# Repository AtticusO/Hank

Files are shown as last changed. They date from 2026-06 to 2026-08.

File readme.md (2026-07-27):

# Hank
Hank is a friendly robotic arm bartender, he can play songs from spotify which the user can select on a locally hosted html page, Hank will also be capable of being controlled through different modes, firstly arrow keys and the press of a key on the keyboard such as r to reset its position, secondly through typed commands, and finally through position adjustment determined by a YOLO inference model which will orient the robot toward the empty cup

## Running Hank (on the Raspberry Pi)

1. **Servo daemon** — the servos use pigpio, which needs its daemon running:
   `sudo pigpiod`
2. **Vision + personality loop** — `python main.py` (camera window, cup/person detection, distance-based reactions)
3. **Keyboard arm control** — `python orientation.py` (arrow keys: left/right = waist, up/down = shoulder, Esc quits)
4. **Servo command line** — `python servo_ops.py` (commands like `jab`, `wave`, `curl`, or angles like `70,50` / `0,70,50`)

## Music page

1. Create a Spotify app at https://developer.spotify.com/dashboard and export:
   `SPOTIPY_CLIENT_ID`, `SPOTIPY_CLIENT_SECRET`, `SPOTIPY_REDIRECT_URI`
2. For playback on the Pi itself install [raspotify](https://github.com/dtcooper/raspotify) so the Pi shows up as a Spotify Connect device (needs Spotify Premium). Otherwise playback goes to any open Spotify app on your account.
3. `python server.py`, then open `http://<pi-ip>:8080` from any phone/laptop on the same network.
   The first run prints a Spotify login URL — open it and paste the redirect URL back into the terminal once.

## Install

```
pip install -r requirements.txt
sudo apt install python3-picamera2   # Pi camera library comes from apt, not pip
```

## TODO (not really in order that much)
1. Adjust 3D models & print and adjust again and print and adjust again
2. Create queue in server.py for song selection
3. Actually make personality.py
4. Clean up servo functions in orientation.py so im not recreating same or similar variables across functions when i dont need to (actually idk about this one its a good idea but most are just writing cords to move_servo() and im sorta of fine with that well see, file does need to be cleaned up a bit tho)
5. Actually attatch cup detection to servo movement
6. Get distance.py working and implement distance detection into movement
7. $ Set up some bash files to automatically configure bluetooth to connect to a PS5 controller $ DONE : WORKS
8. Make mock servos so I can test on devices other than rasp pi
9. Wire buttons and implement code for choosing mode of operation such as bartender or controlled
10. Make dance functions with bpm from spotify
11. Add all the infrastructure for raspotify 
12. Tie everything together in a somewhat cohesive process in main.py

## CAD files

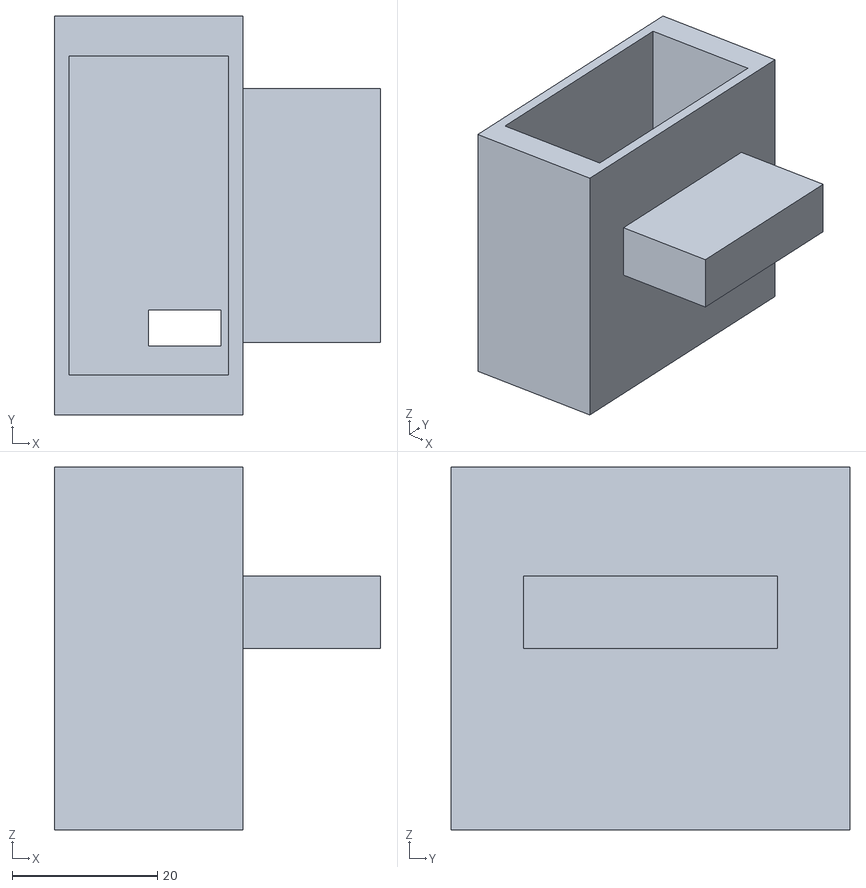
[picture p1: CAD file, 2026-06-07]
Design/H-1/Elbow_Servo_Case-Body.stl
45.0 x 55.0 x 50.0

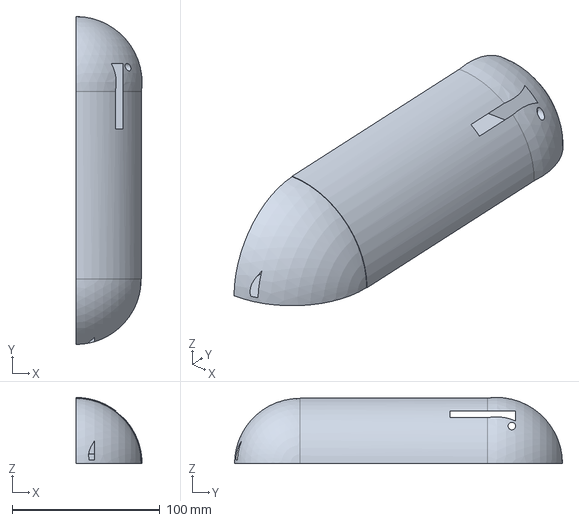
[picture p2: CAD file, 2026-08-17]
Design/H-2/Arm_Two.FCStd
44.8 x 222.0 x 44.8 mm

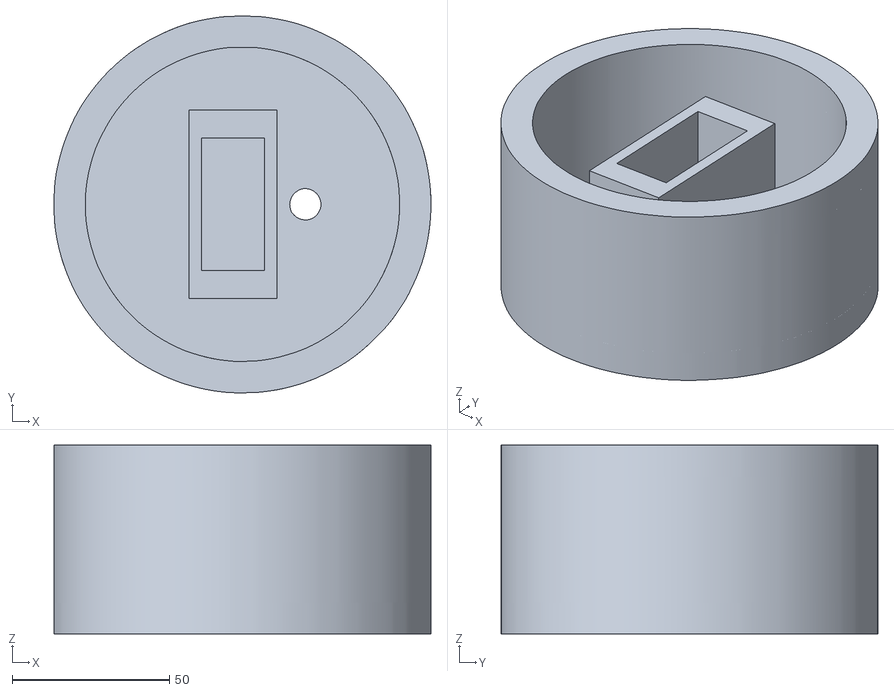
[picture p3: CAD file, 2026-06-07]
Design/H-1/Servo_Base_Cyl_Attatchment.stl
119.9 x 119.8 x 60.0

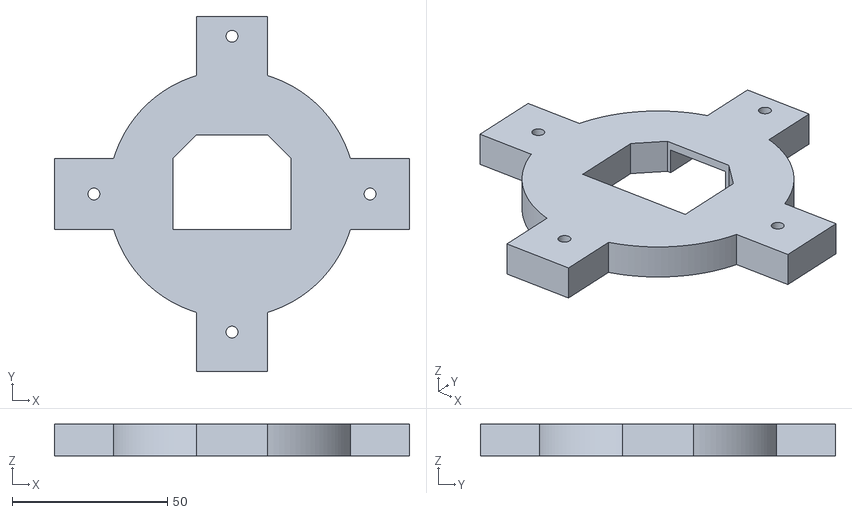
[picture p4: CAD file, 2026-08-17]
Design/H-2/Waist_Adapter_Two-Body.stl
114.3 x 114.3 x 10.2

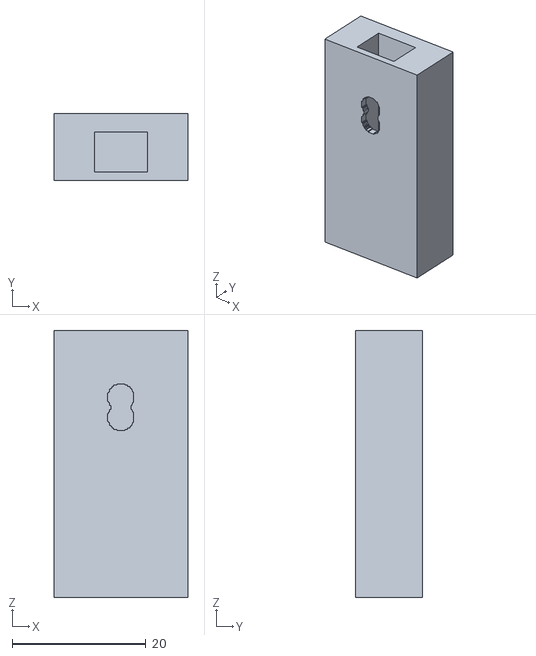
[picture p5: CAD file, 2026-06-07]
Design/H-1/Servo_Adapter.stl
20.0 x 10.0 x 40.0

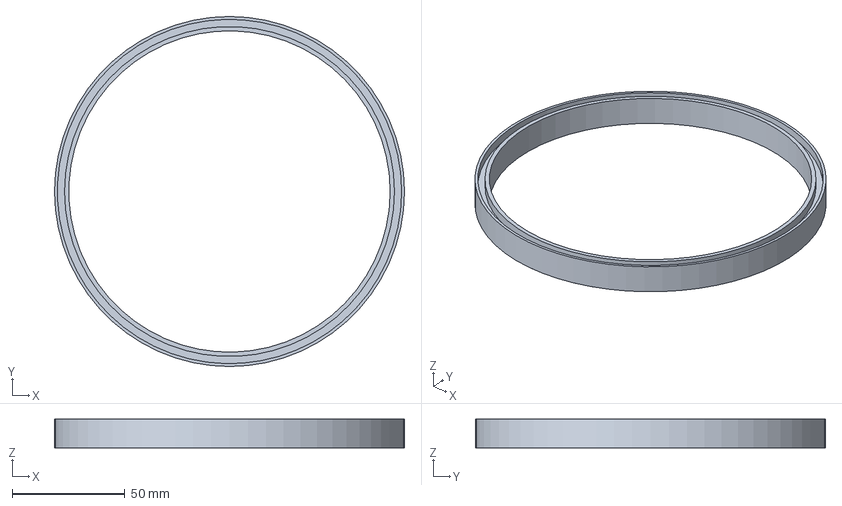
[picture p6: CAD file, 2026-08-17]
Design/H-2/Waist_Ball_Bearing_Cage.FCStd
154.9 x 154.9 x 12.7 mm

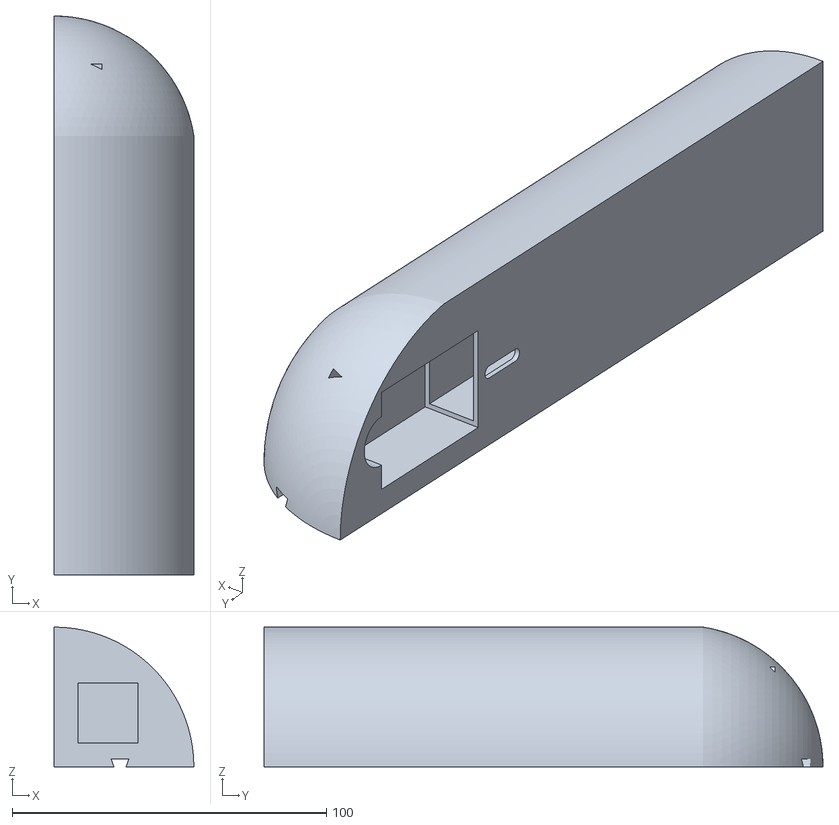
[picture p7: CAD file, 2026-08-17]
Design/H-2/ForeArm_Two-Body.stl
44.5 x 177.8 x 44.5

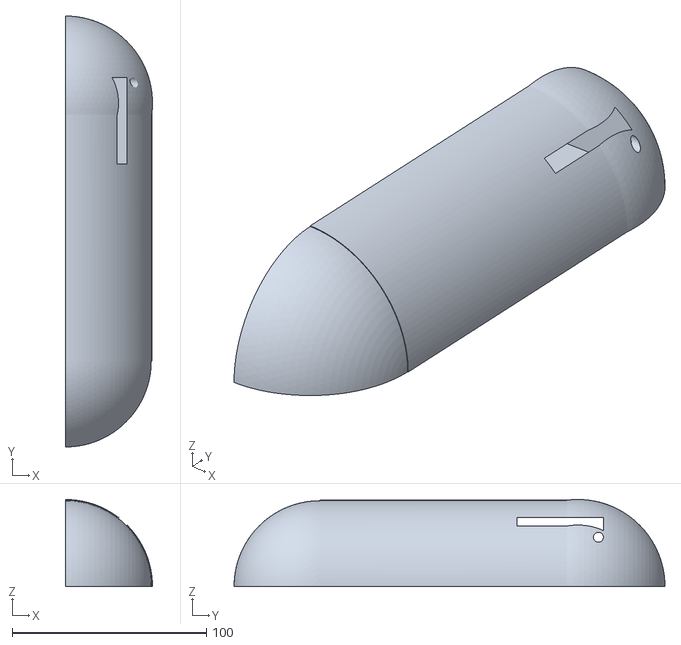
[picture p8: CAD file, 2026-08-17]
Design/H-2/Arm_Two-Body.stl
44.8 x 222.0 x 44.8

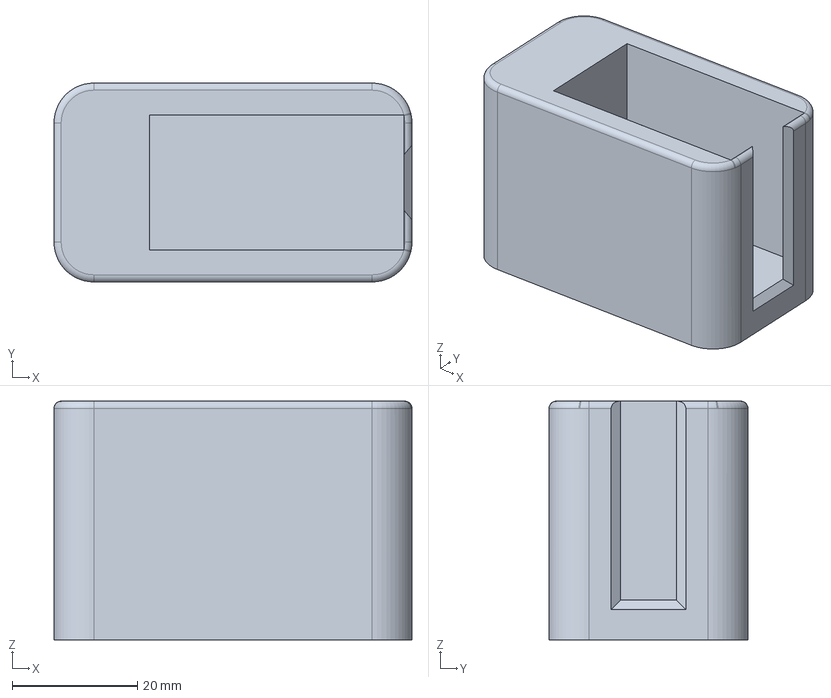
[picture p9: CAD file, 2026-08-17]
Design/H-2/Servo_Case_Two.FCStd
57.1 x 31.8 x 38.1 mm

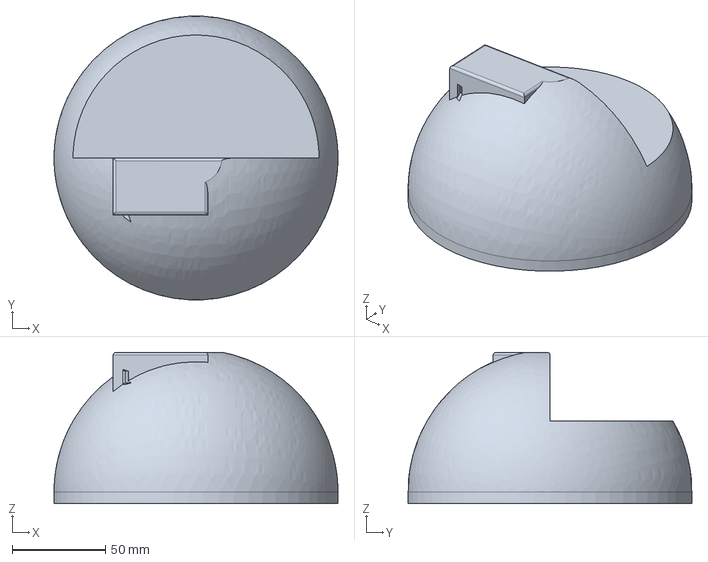
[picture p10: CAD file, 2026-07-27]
Design/H-2/Hemisphere_Two.FCStd
152.4 x 152.2 x 81.3 mm

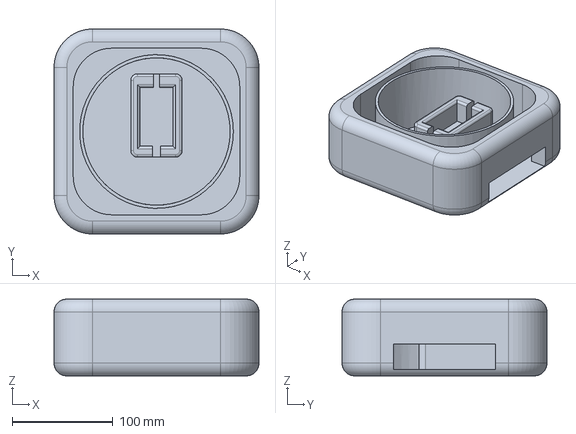
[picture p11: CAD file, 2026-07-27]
Design/H-2/Square_Base_Two.FCStd
203.2 x 203.2 x 76.2 mm

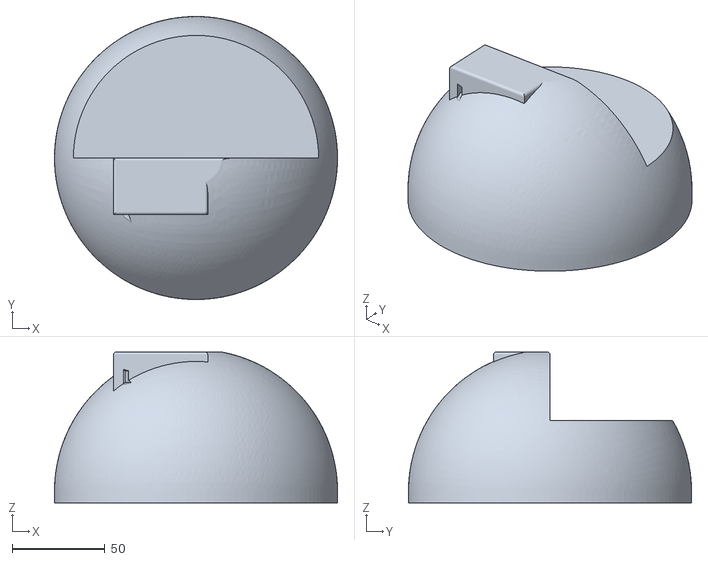
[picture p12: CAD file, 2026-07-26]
Design/H-2/Hemisphere_Two-Body.stl
152.4 x 152.4 x 81.3

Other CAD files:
Design/H-2/Waist_Ball_Bearing_Cage-Body.stl
Design/H-2/Waist_Adapter_Two.FCStd
Design/H-2/Servo_Case_Two-Body.stl
Design/H-2/Square_Base_Two-Body.stl
Design/H-2/ForeArm_Two.FCStd

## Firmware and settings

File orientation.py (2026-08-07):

import servo_ops
import asyncio
import time
from evdev import InputDevice, list_devices, categorize, ecodes
import select

class positions:
    def __init__(self):
        self.servos = servo_ops.move()
        self.orient = {"waist" : self.servos.angles["waist"],
                       "shoulder" : self.servos.angles["shoulder"],
                       "elbow" : self.servos.angles["elbow"]}
        self.pos_log = []
        for tags in self.orient:
            self.pos_log.append(self.orient[tags])

    ## Keeps orient/pos_log in sync with what the servos actually did,
    ## since the servo layer clamps angles to [-90, 90]
    def _sync_state(self):
        for i, name in enumerate(("waist", "shoulder", "elbow")):
            self.orient[name] = self.servos.angles[name]
            self.pos_log[i] = self.servos.angles[name]

    def _sync_logs(self):
        for i, n in enumerate(("waist", "shoulder", "elbow")):
            self.orient[n] = self.pos_log[i]


    ## Moves servos asyncronously
    ## servo_pos is a list of [waist, shoulder, elbow] positions
    async def move_servo(self, servo_pos, delays=None):
        for i in range(len(servo_pos)):
            #print(servo_pos[i])
            #print(f"MOVING TO :: {servo_pos[i]}")
            await asyncio.gather(
                self.servos.move_waist(servo_pos[i][0]),
                self.servos.move_shoulder(servo_pos[i][1]),
                self.servos.move_elbow(servo_pos[i][2])
            )
            if delays and i < len(delays) and delays[i] is not None:
                await asyncio.sleep(delays[i])
            self._sync_state()

    ## generates and returns servo positional array, posit_array, instead of directly calling servo movement
    ## output from these functions get passed into the move_servo() function to update servo position
    ## all of these functions return a list of servo degree positions in a [[waist,shoulder,elbow]] format
    def waist(self, deg):
        new_pos = int(self.orient["waist"] + deg)
        return [[new_pos, self.orient["shoulder"], self.orient["elbow"]]]

    def shoulder(self, deg):
        new_pos = int(self.orient["shoulder"] + deg)
        return [[self.orient["waist"], new_pos, self.orient["elbow"]]]

    def elbow(self, deg):
        new_pos = int(self.orient["elbow"] + deg)
        return [[self.orient["waist"], self.orient["shoulder"], new_pos]]

    ## Additive Rotations for servos
    ## These are plain sync methods: each one is a single top-level
    ## asyncio.run() call, so they can be used from normal code anywhere
    ## Changes waist position incrementally
    def rotate_waist(self, deg):
        asyncio.run(self.move_servo(self.waist(deg), [0.1]))

    ## Changes shoulder position incrementally
    def rotate_shoulder(self, deg):
        asyncio.run(self.move_servo(self.shoulder(deg), [0.1]))

    ## Changes elbow position incrementally
    def rotate_elbow(self, deg):
        asyncio.run(self.move_servo(self.elbow(deg), [0.1]))

    ###########################
    ### Arm Movements for keyboard control
    def reach(self, deg):
        new_shoulder = self.orient["shoulder"] + deg

        ## elbow follows the shoulder a little further to keep the reach straight
        if deg > 0:
            new_elbow = self.orient["elbow"] + deg + 10
        elif deg < 0:
            new_elbow = self.orient["elbow"] + deg - 10
        else:
            new_elbow = self.orient["elbow"]

        posit_array = [[self.orient["waist"], new_shoulder, new_elbow]]
        asyncio.run(self.move_servo(posit_array))

    def rotate(self, deg):
        new_pos = self.orient["waist"] + deg
        posit_array = [[new_pos, self.orient["shoulder"], self.orient["elbow"]]]
        asyncio.run(self.move_servo(posit_array))


    #### Preset Movements and Orientations

    ## Dance Moves and stuff
    def dance(self, bpm, playing=True):
        sync = abs(int((bpm / 60)*3))
        self.center()
        self.bounce(sync, "right")
            #time.sleep(1)
            #self.bounce(sync, "left")
            #time.sleep(1)

    def bounce(self, rate, dir):
        ## Capture the start pose once so the return waypoint is exact even
        ## if the extended pose gets clamped by the servo layer.
        base = list(self.pos_log)
        sign = -1 if dir == "left" else 1
        print("LEFT" if sign < 0 else "RIGHT")

        ## Arc out to the side (waist swings in `dir`, shoulder lifts, elbow
        ## tucks), then return to the captured base pose.
        out = [base[0] + sign * rate, base[1] + rate, base[2] - rate]
        back = [base[0], base[1], base[2]]

        pos = [out, back]
        delays = [0.5, 0.3]

        print(f"Pos: {pos}\nRate: {rate}\nDir: {dir}")
        asyncio.run(self.move_servo(pos, delays))
        


    ## Sets orientation for fist bump and loads to servo
    def fist_bump(self):
        posit_array = []
        delays = []
        if self.orient["shoulder"] != 70 or self.orient["elbow"] != 50:
            posit_array.append([0, 70, 50])
            delays.append(0.5)
        posit_array.append([0, 20, -10])
        delays.append(1)
        posit_array.append([0, 70, 50])
        delays.append(0.5)

        asyncio.run(self.move_servo(posit_array, delays))

    def jab(self):
        posit_array = []
        delays = []
        if self.orient["shoulder"] != 70 or self.orient["elbow"] != 50:
            posit_array.append([0, 70, 50])
            delays.append(0.2)
        posit_array.append([0, -40, -80])
        delays.append(0.1)
        posit_array.append([0, 70, 50])
        delays.append(0.1)

        asyncio.run(self.move_servo(posit_array, delays))

    def reset(self):
        asyncio.run(self.move_servo([[0, 70, 50]], [0.5]))

    def curl(self):
        asyncio.run(self.move_servo([[0, 0, 90]], [0.4]))

    def point(self):
        asyncio.run(self.move_servo([[0, 0, -90]], [0.2]))

    def center(self):
        asyncio.run(self.move_servo([[45, 45, 45]], [0.1]))
    ### Different Waves for greetings
    def wave(self):
        posit_array = []
        delays = []
        posit_array.append([0, 70, self.orient["elbow"]])
        delays.append(0.4)
        posit_array.append([0, 70, 50])
        delays.append(0.01)
        posit_array.append([0, 70, -30])
        delays.append(0.2)
        posit_array.append([0, 70, 50])
        delays.append(0.01)
        posit_array.append([0, 70, -30])
        delays.append(0.2)

        asyncio.run(self.move_servo(posit_array, delays))
        self.reset()

    def wave_one(self):
        posit_array = []
        delays = []
        posit_array.append([0, 70, self.orient["elbow"]])
        delays.append(0.4)
        posit_array.append([0, 70, 50])
        delays.append(0.01)
        posit_array.append([0, 70, -30])
        delays.append(0.2)
        posit_array.append([0, 70, 50])
        delays.append(0.01)
        posit_array.append([0, 70, -30])
        delays.append(0.2)

        asyncio.run(self.move_servo(posit_array, delays))
        self.reset()

    def wave_two(self):
        posit_array = []
        delays = []
        posit_array.append([0, 70, -90])
        delays.append(0.4)
        posit_array.append([20, self.orient["shoulder"], self.orient["elbow"]])
        delays.append(0.01)
        posit_array.append([0, self.orient["shoulder"], self.orient["elbow"]])
        delays.append(0.2)
        posit_array.append([-20, self.orient["shoulder"], self.orient["elbow"]])
        delays.append(0.01)

        asyncio.run(self.move_servo(posit_array, delays))
        self.reset()

    def bounce_left(self):
        posit_array = []
        delays = []
        posit_array.append([-30, 30, 10])
        delays.append(0.2)
        posit_array.append([-70, 70, 50])
        delays.append(0.01)
        posit_array.append([-30, 30, 10])
        delays.append(0.2)
        posit_array.append([0, 70, 50])
        delays.append(0.2)

        asyncio.run(self.move_servo(posit_array, delays))
        self.reset()

    def bounce_right(self):
        posit_array = []
        delays = []
        posit_array.append([30, 30, 10])
        delays.append(0.2)
        posit_array.append([70, 70, 50])
        delays.append(0.01)
        posit_array.append([30, 30, 10])
        delays.append(0.2)
        posit_array.append([0, 70, 50])
        delays.append(0.2)

        asyncio.run(self.move_servo(posit_array, delays))
        self.reset()

    ## Keyboard hold controls

    def find_keyboard(self):
        for path in list_devices():
            dev = InputDevice(path)
            keys = dev.capabilities().get(ecodes.EV_KEY, [])
            if ecodes.KEY_A in keys and ecodes.KEY_UP in keys:
                return dev
        raise RuntimeError("No keyboard found in /dev/input")

    def listen_hold(self):
        """Hold-aware loop: tracks which keys are currently held and acts
        repeatedly while they stay down, independent of OS key-repeat rate.
        Left/right rotate the waist, up/down raise/lower the shoulder."""
        dev = self.find_keyboard()
        print(f"Listening on {dev.path} ({dev.name})")
        held = set()

        while True:
            # Wait up to 0.05s for input; returns immediately if a key event is ready.
            r, _, _ = select.select([dev.fd], [], [], 0.05)
            if r:
                for event in dev.read():
                    if event.type != ecodes.EV_KEY:
                        continue
                    key = categorize(event)
                    if key.keystate == key.key_down:
                        held.add(key.keycode)
                    elif key.keystate == key.key_up:
                        held.discard(key.keycode)

            if "KEY_ESC" in held:
                break

            # This block runs ~20x/sec for as long as a key stays held.
            moved = False
            if "KEY_UP" in held:
                print("UP PRESSED")
                self.pos_log[1] -= 5
                moved = True

            if "KEY_DOWN" in held:
                print("DOWN PRESSED")
                self.pos_log[1] += 5
                moved = True

            
            if "KEY_LEFT" in held:
                print("LEFT PRESSED")
                self.pos_log[0] -= 5
                moved = True

            if "KEY_RIGHT" in held:
                print("RIGHT PRESSED")
                self.pos_log[0] += 5
                moved = True

            
            
            if "KEY_W" in held:
                print("LEFT PRESSED")
                self.pos_log[2] -= 5
                moved = True

            if "KEY_E" in held:
                print("RIGHT PRESSED")
                self.pos_log[2] += 5
                moved = True
            
            if "KEY_A" in held:
                print("LEFT PRESSED")
                self.pos_log[1] -= 5
                moved = True

            if "KEY_D" in held:
                print("RIGHT PRESSED")
                self.pos_log[1] += 5
                moved = True
            
            if "KEY_Z" in held:
                print("LEFT PRESSED")
                self.pos_log[0] -= 5
                moved = True

            if "KEY_X" in held:
                print("RIGHT PRESSED")
                self.pos_log[0] += 5
                moved = True




            if "KEY_R" in held:
                print("RESET PRESSED")
                self.reset()
            if "KEY_P" in held:
                print("POINT PRESSED")
                self.point()
            if "KEY_C" in held:
                print("CURL PRESSED")
                self.curl()
            if moved:
                # move_servo expects a list of [waist, shoulder, elbow] rows
                asyncio.run(self.move_servo([list(self.pos_log)]))

    ## Keyboard press controls
    def listen_press(self):
        dev = self.find_keyboard()

        print(f"Listening on {dev.path} ({dev.name})")
        for event in dev.read_loop():
            if event.type != ecodes.EV_KEY:
                continue
            key = categorize(event)
            if key.keystate != key.key_down:   # only on press, ignore release/hold
                continue
            if key.keycode == "KEY_UP":
                print("UP PRESSED")
                self.reach(-30)
            elif key.keycode == "KEY_DOWN":
                print("DOWN PRESSED")
                self.reach(30)
            elif key.keycode == "KEY_LEFT":
                print("LEFT PRESSED")
                self.rotate(30)
            elif key.keycode == "KEY_RIGHT":
                print("RIGHT PRESSED")
                self.rotate(-30)
            elif key.keycode == "KEY_R":
                print("RESET PRESSED")
                self.reset()
            elif key.keycode == "KEY_C":
                print("CURL PRESSED")
                self.curl()
            elif key.keycode == "KEY_ESC":
                break


if __name__ == "__main__":
    p = positions()
    print("\n $$$   Hank Orientation System   $$$ \n")
    settings = 2
    if settings == 0:
        print("Keyboard Controls: \n")
        p.reset()
        p.listen_hold()
    elif settings == 1:
        while True:
            print("\n")
            x = input("Enter Orientation >>> ")
            print("\n")
            if x == "curl" or x == "cu":
                p.curl()
            elif x == "fb" or x == "b":
                p.fist_bump()
            elif x == "reset" or x == "r":
                p.reset()
            elif x == "wave" or x == "w":
                p.wave()
            elif x == "point" or x == "p" or x == "pt":
                p.point()
            elif x == "jab" or x == "j":
                p.jab()
            elif x == "br":
                p.bounce_right()
            elif x == "bl":
                p.bounce_left()
            elif x == "waist":
                p.rotate_waist(10)
                time.sleep(0.5)
                p.rotate_waist(-10)
    elif settings == 2:
        bpm = input("Enter BPM >>> ")
        p.dance(int(bpm))
        #p.bounce(20, "right")

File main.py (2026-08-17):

import cam_ops
import obj_detection
import personality
import orientation
#import distance
import cv2
#import ps5_controls
import server


class Hank:
    ## Hank owns every piece of hardware exactly once and shares references;
    ## creating a second Cam or servo stack crashes on the Pi
    def __init__(self):
        self.cam = cam_ops.Cam(0)
        self.detector = obj_detection.detect()
        self.arm = orientation.positions()
        #self.measure = distance.measure()
        self.pers = personality.acts(self.arm)
        self.ps5 = None



    def detect(self, frame):
        annotated_frame, tags, cords = self.detector.detection(frame)
        return annotated_frame, tags, cords

    def video(self):
        f_count = 0
        while True:
            frame = self.cam.stream()
            if frame is None:
                continue

            annotated_frame, tags, cords = self.detect(frame)
            f_count += 1

            ## React every few frames so servo moves don't stall the video
            if f_count > 2 and len(tags) > 0:
                #d = self.measure.dist()
                self.pers.follow(tags, cords)
                f_count = 0

            cv2.imshow("Hank View", annotated_frame)
            if cv2.waitKey(1) == ord('q'):
                break
        cv2.destroyAllWindows()
        self.cam.stop()

    ## Mode control, setting mode 0 is bartender, mode 1 is keys control ([w,e],[a,d],[z,x]), 
    ## setting mode 2 is PS5 Controller
    def mode(self, setting):
        if setting == 1:
            self.arm.reset()
            self.arm.listen_hold()
        elif setting == 2:
            pass
            #self.ps5 = ps5_controls.Controller(self.arm)
            #while True:
            #    c.remote()
            #    if c.cancel == True:
            #        break
        elif setting == 3:
            print("Starting Hank Music Server")
            server._start_server()
        

if __name__ == "__main__":
    print("Executing Hank Protocals")
    h = Hank()
    setting = 0
    if setting != 0:
        h.mode(setting)
    else:
        h.video()

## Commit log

2026-06-07 Add file structure and add cam_ops and detection
    [Arm_Two.FCStd, Elbow_Servo_Case-Body.stl, Servo_Adapter.stl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]
2026-06-09 Arm Two stl file upload
    [Arm_Two-Body.stl, Arm_Two.FCStd]
2026-06-11 Editted Arm Designs, also added to servo ops, using gpiozero for servos
    [Arm_Two-Body.stl, Arm_Two.FCStd, Elbow_Servo_Case-Body.stl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]
2026-06-12 Added to servo_ops and made functions async for smoother servos
2026-06-12 set up servo movement and added hardcoded moves, need to make into functions
2026-06-12 tested on pi and servo code works, fixed bugs in orientation and added loop to take input to call position functions
    [orientation.py, servo_ops.py]
2026-06-14 fixed yolo model bugs on raspberry pi,hook up servos to computer vision to a degree, waist servo not working idk why
    [cam_ops.py, main.py, obj_detection.py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]
2026-06-15 added some orientations, waist now moves with avg x value of an identified person, need battery pack because pi crashes when i move all three servos
    [orientation.py, personality.py, servo_ops.py]
2026-06-16 created square base, edited forearm, some minor code changes
    [Arm_Two - Copy.FCStd, ForeArm_Two-Body.stl, ForeArm_Two.FCStd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]
2026-06-18 updated 3d models like square base two and hemisphere two, added structures to measure distance, altered personality to act as more of a module and created structure for reactions to distance
    [Hemisphere_Two.FCStd, Servo_Case_Two.FCStd, Square_Base_Two.FCStd]
2026-06-23 stl file stuff, servo case adn hemisphere changes
    [Hemisphere_Two-Body.stl, Hemisphere_Two.FCStd, Servo_Case_Two-Body.stl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]
2026-06-26 Fixed Arrow Controls on rasp pi
    [cam_ops.py, music.py, orientation.py]
2026-06-28 Added some arrow key hold control features, needs to be fixed because theres an error with how the async function are running when calling servo movemnet functions for arrow key controls, i just put 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
    [music.py, orientation.py]
2026-07-08 fixed async issues im pretty sure maybe
    [music.py, orientation.py]
2026-07-13 added alot, fixed async function issue with key controls, changed library used for server to http.server and urllib instead of socket and uses json to play songs from the index.html file which is hos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
    [cam_ops.py, distance.py, main.py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]
2026-07-14 finally wired battery to servos so i can control all 3 motors without crashing the pi, works pretty good, distance thing is still not working well might have to replace the part
    [distance.py, orientation.py]
2026-07-15 Added a python file to allow controll through a ps5 controller, left stick shoulder right stick elbow and triggers for waist, got stick pos detection just need to connect to servos right way through 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
    [orientation.py, ps5_controls.py]
2026-07-17 added other features to ps5 file such as buttons mapped to commands like curl jab or reset, also added trigger detection mapped to the waist servo to rotate the arm
    [ps5_controls.py]
2026-07-23 built out spotipy so i have authentication set up so music playing through the lan site will be done soon
    [Hemisphere_Two.FCStd, Square_Base_Two-Body.stl, Square_Base_Two.FCStd]
2026-07-23 fixed music uri redirect errors and also fixed errors in server.py, spotipy now works pretty well i just wanna adjust the html a bit in index.html but its looking good for now, need to write code to 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
    [music.py, server.py]
2026-07-25 Adjusted models because I fixed my ender 3 so i can acutally print now, server.py prints the correct lan ip now and starts spotify before doing anything that needs it maybe i will start spotify in th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
    [Hemisphere_Two-Body.stl, Hemisphere_Two.FCStd, Square_Base_Two-Body.stl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]
2026-07-26 added basic stuff for dance functions in orientation.py, also changed some stuff about the Arm 3d design and also fixed issues with the circular base 3d design, need to test the basic stuff for dance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
    [Arm_Two.FCStd]
2026-07-26 built out bounce and dance a little more, not actually working on the servos, will fix tomorrow cause idk why the seros arent moving because the orient dictionary and pos log list is updating on call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
    [orientation.py]
2026-07-26 added a bash file to configure bluetooth connection, I need to write code to run it in main when ps5 controller mode is in use, I also added a mode function to main.py which handles which mode the ro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
    [main.py, orientation.py, ps5_controls.py]
2026-07-27 Maybe possibly might of fixed bounce function in orientation so dance function might work now, also worked on servo case 3d design because the square base finally finished printing after 2.5 days als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
    [Hemisphere_Two.FCStd, Servo_Case_Two.FCStd, Square_Base_Two.FCStd]
2026-07-31 fixed dance to some extent, still need to make it actually bounce to a bpm and also make the bouncing look good, set up raspotify stuff and got it configured with the spotipy stuff
    [main.py, orientation.py, ps5_controls.py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]
2026-08-07 so ive just been adding stuff whenever i feel like it for the past few days so i might miss something but i made a function to call to start the server so when the server needs to be started through 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
    [main.py, orientation.py, ps5_controls.py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]
2026-08-10 added basic mock_serovs.py file, need to actually figure out how that is going to work by looking at how i use the servos and stuff but i want to get that done so i can develope stuff on my laptop ea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
    [Arm_Two - Copy.FCStd, Arm_Two-Body.stl, Arm_Two.FCStd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]
2026-08-19 Added a startup bash script which executes things like pigpiod for servos and starts raspotify need to figure out how i will run with needed privaleges but theres a few ways to do that just havent de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
